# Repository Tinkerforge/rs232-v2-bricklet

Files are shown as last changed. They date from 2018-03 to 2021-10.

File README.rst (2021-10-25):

RS232 Bricklet 2.0
==================

This repository contains the firmware source code and the hardware design
files. The documentation generator configs can be found at
https://github.com/Tinkerforge/generators

Repository Content
------------------

software/:
 * examples/: Examples for all supported languages
 * build/: Compiled files
 * src/: Source code of firmware
 * Makefile: Makefile to build project

hardware/:
 * Contains KiCad project files and additionally schematics as PDF

datasheets/:
 * Contains datasheets for sensors and complex ICs that are used

Hardware
--------

The hardware is designed with the open source EDA Suite KiCad
(http://www.kicad.org). Before you are able to open the files,
you have to install the Tinkerforge kicad-libraries
(https://github.com/Tinkerforge/kicad-libraries). You can either clone
them directly in hardware/ or clone them in a separate folder and
symlink them into hardware/
(ln -s kicad_path/kicad-libraries project_path/hardware). After that you
can open the .pro file in hardware/ with KiCad and from there view and
modify the schematics and the PCB layout.

Software
--------

If you want to do your own Brick/Bricklet firmware development we highly
recommend that you use our build environment setup script and read the
tutorial (https://www.tinkerforge.com/en/doc/Tutorials/Tutorial_Build_Environment/Tutorial.html).

To compile the C code we recommend you to install the newest GNU Arm Embedded
Toolchain (https://launchpad.net/gcc-arm-embedded/+download).
You also need to install bricklib2 (https://github.com/Tinkerforge/bricklib2).

You can either clone it directly in software/src/ or clone it in a
separate folder and symlink it into software/src/
(ln -s bricklib_path/bricklib2 project_path/software/src/). Finally make sure to
have CMake installed (http://www.cmake.org/cmake/resources/software.html).

After that you can build the firmware by invoking make in software/.
The firmware (.zbin) can then be found in software/build/ and uploaded
with brickv (click button "Flashing" on start screen).

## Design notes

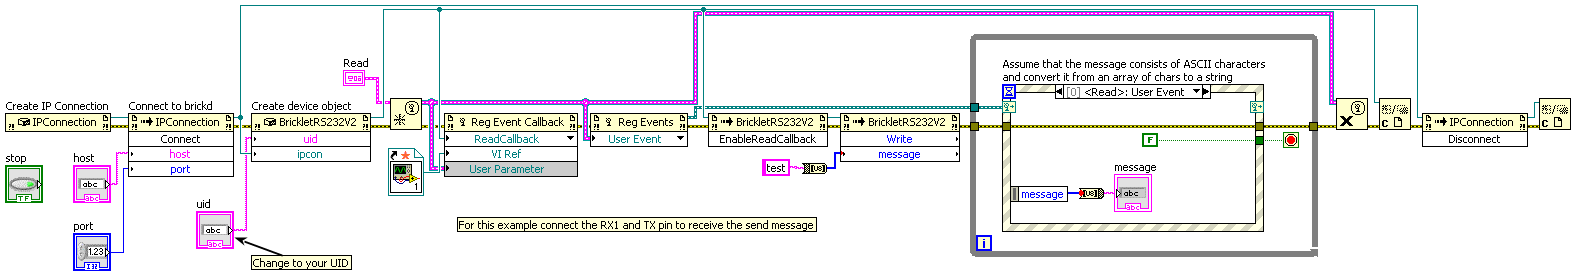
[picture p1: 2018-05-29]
software/examples/labview/Example Loopback.vi.png

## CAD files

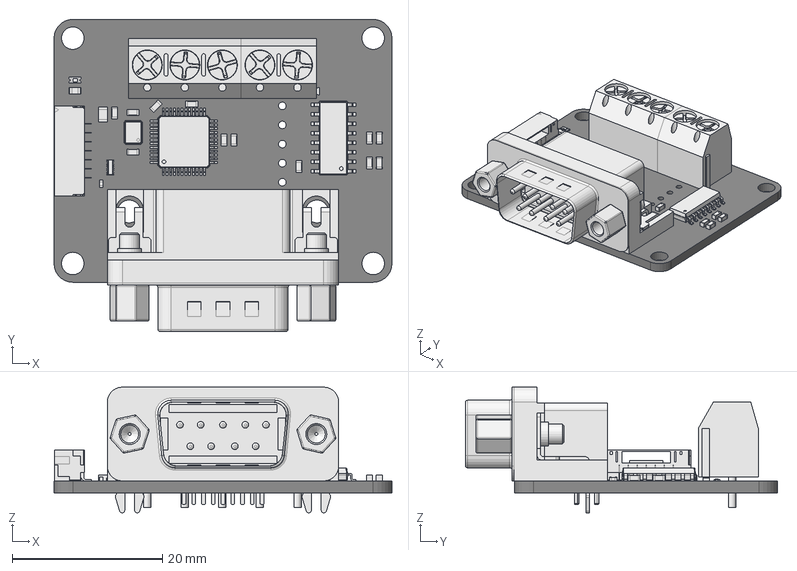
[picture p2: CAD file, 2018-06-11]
hardware/rs232-v2.FCStd
45.0 x 41.6 x 16.8 mm
Pcb
C_0603_
soic_16_39x99_p127_
lqfp48_7x7_p05_
BrickletConn_7pin_
D_0603_blue_
C_0603_001
C_0603_002
C_0603_003
C_0603_004
C_0603_005
C_0603_006
C_0603_007
C_0603_008
DSUB9-Male_
C_0402_
C_0603_009
C_0805_
C_0603_010
C_0603_011
R_0603_

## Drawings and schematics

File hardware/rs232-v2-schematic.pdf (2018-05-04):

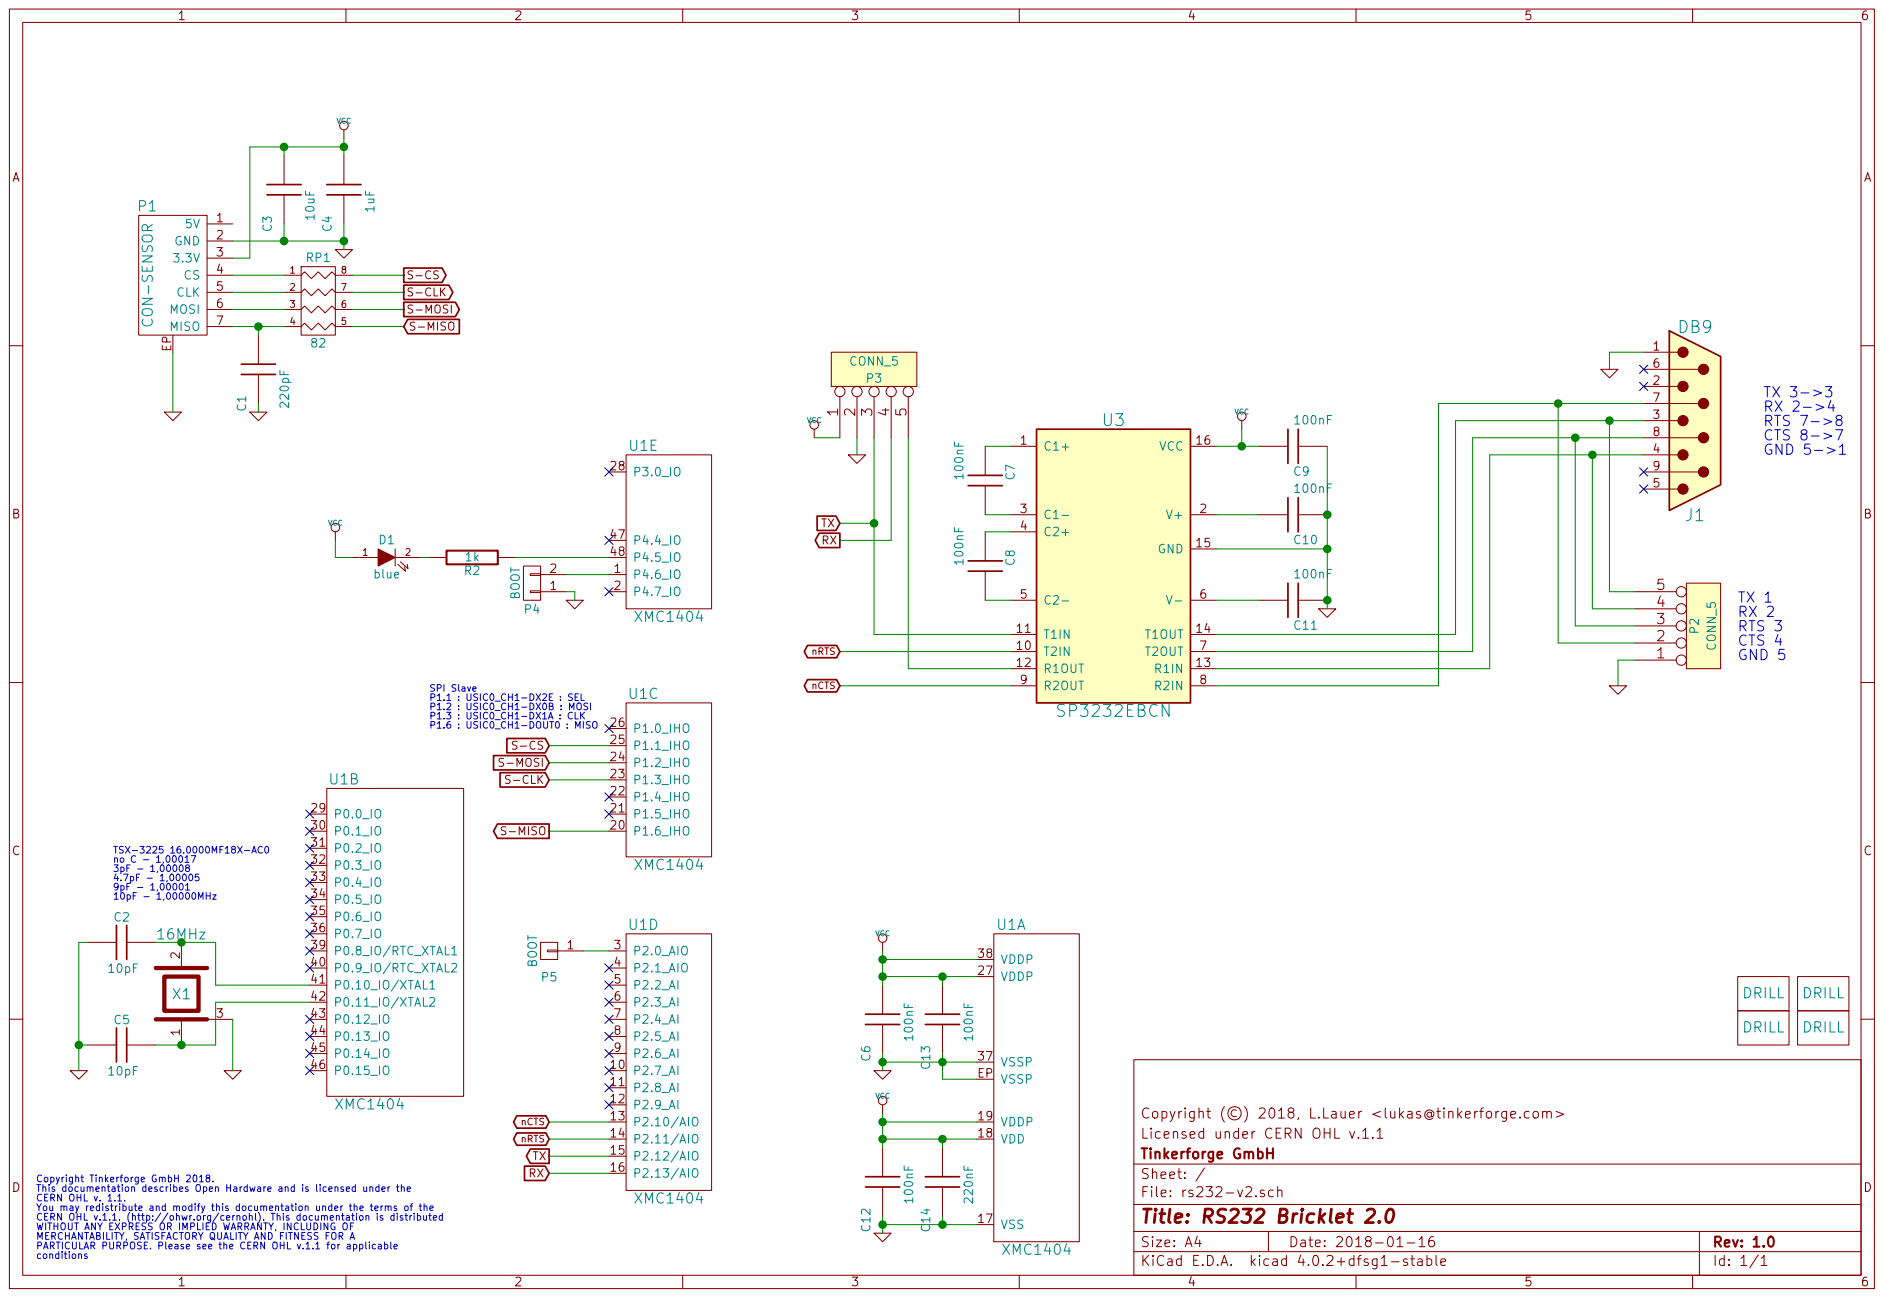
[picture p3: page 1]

GND 5->1 TX 1 RX 2 RTS 3

SPI Slave P1.1 : USIC0_CH1-DX2E : SEL P1.2 : USIC0_CH1-DX0B : MOSI P1.3 : USIC0_CH1-DX1A : CLK

Licensed under CERN OHL v.1.1 Copyright (©) 2018, L.Lauer <lukas@tinkerforge.com>

File: rs232-v2.sch Sheet: / Tinkerforge GmbH

Copyright Tinkerforge GmbH 2018. This documentation describes Open Hardware and is licensed under the CERN OHL v. 1.1. You may redistribute and modify this documentation under the terms of the CERN OHL v.1.1. (http://ohwr.org/cernohl). This documentation is distributed WITHOUT ANY EXPRESS OR IMPLIED WARRANTY, INCLUDING OF MERCHANTABILITY, SATISFACTORY QUALITY AND FITNESS FOR A

PARTICULAR PURPOSE. Please see the CERN OHL v.1.1 for applicable

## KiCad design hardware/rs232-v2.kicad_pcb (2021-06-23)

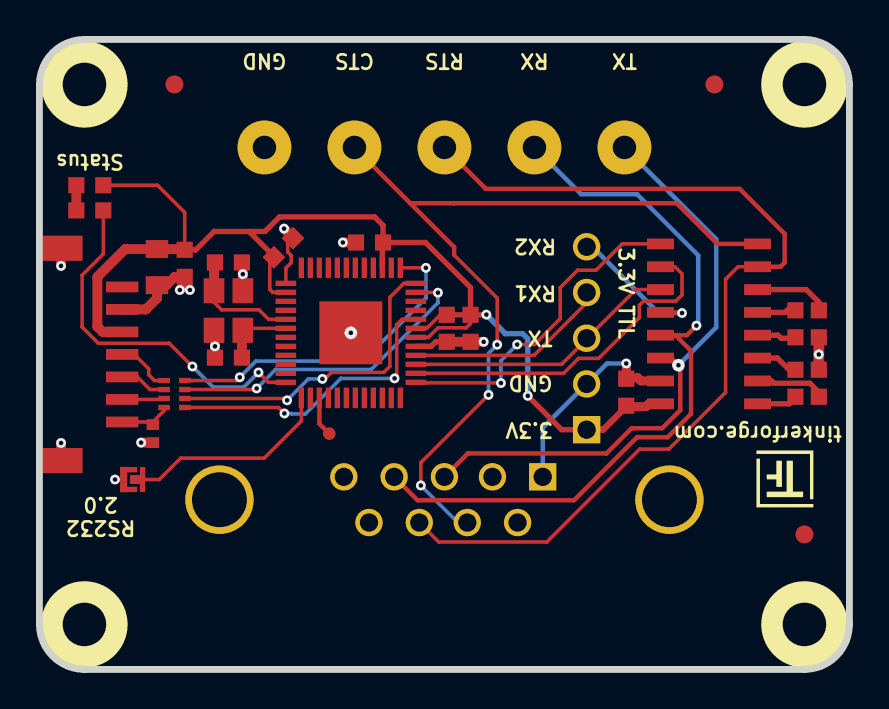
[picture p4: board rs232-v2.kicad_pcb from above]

Board: 2 copper layers, 45.0 x 35.0 mm, 35 parts (0 on the bottom side), 31 nets.

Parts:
C1: 220pF; C0402F
C2, C5: 10pF; C0603F
C3: 10uF; C0805
C4: 1uF; C0603F
C6, C7, C8, C9, C10, C11, C12, C13: 100nF; C0603F
C14: 220nF; C0603F
D1: blue; D0603F
Fiducial_Mark: VAL**; Fiducial_Mark
Fiducial_Mark#2, Fiducial_Mark#3: VAL**; Fiducial_Mark
J1: DB9; SUB09-EU
P1: CON-SENSOR; CON-SENSOR2
P2: CONN_5; AKL_5_5
P3: CONN_5; pin_array_5x1
P4: BOOT; SolderJumper
P5: BOOT; DEBUG_PAD
R2: 1k; R0603F
RP1: 82; 4X0402
U1: XMC1403; QFN48-EP2
U3: SP3232EBCN; SOIC16
U4, U5, U6, U7: DRILL; DRILL_NP
VAL: CE_5mm
VAL#2: WEEE_7mm
X1: 16MHz; CRYSTAL_3225

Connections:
GND: C1.1, C2.1, C3.1, C4.1, C5.1, C6.1, C9.1, C10.1, C11.1, C12.1, C13.1, C14.1, J1.1, P1.2, P1.EP, P2.1, P3.2, P4.1, U1.17, U1.37, U1.EP, U3.15, X1.3
unnamed: C1.2, P1.7, RP1.4
unnamed: C2.2, U1.41, X1.2
unnamed: C5.2, U1.42, X1.1
unnamed: C7.1, U3.1
unnamed: C7.2, U3.3
unnamed: C8.1, U3.4
unnamed: C8.2, U3.5
unnamed: C10.2, U3.2
unnamed: C11.2, U3.6
unnamed: D1.2, R2.2
unnamed: J1.3, P2.5, U3.14
unnamed: J1.4, P2.4, U3.13
unnamed: J1.7, P2.2, U3.8
unnamed: J1.8, P2.3, U3.7
unnamed: P1.4, RP1.1
unnamed: P1.5, RP1.2
unnamed: P1.6, RP1.3
unnamed: P3.5, U3.12
unnamed: P4.2, U1.1
unnamed: P5.1, U1.3
unnamed: R2.1, U1.48
RX: P3.4, U1.16
S-CLK: RP1.7, U1.23
S-CS: RP1.8, U1.25
S-MISO: RP1.5, U1.20
S-MOSI: RP1.6, U1.24
TX: P3.3, U1.15, U3.11
VCC: C3.2, C4.2, C6.2, C9.2, C12.2, C13.2, C14.2, D1.1, P1.3, P3.1, U1.18, U1.19, U1.27, U1.38, U3.16
nCTS: U1.13, U3.9
nRTS: U1.14, U3.10

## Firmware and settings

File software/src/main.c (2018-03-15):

/* rs232-v2-bricklet
 * Copyright (C) 2018 Ishraq Ibne Ashraf <ishraq@tinkerforge.com>
 *
 * main.c: Initialization for RS232 V2 Bricklet
 *
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
 * You should have received a copy of the GNU Lesser General Public
 * License along with this library; if not, write to the
 * Free Software Foundation, Inc., 59 Temple Place - Suite 330,
 * Boston, MA 02111-1307, USA.
 */

#include <stdio.h>
#include <stdbool.h>

#include "bricklib2/bootloader/bootloader.h"
#include "bricklib2/hal/system_timer/system_timer.h"
#include "bricklib2/logging/logging.h"

#include "configs/config.h"
#include "communication.h"
#include "rs232.h"

int main(void) {
	logging_init();
	logd("Start RS232 V2 Bricklet\n\r");

	communication_init();
	rs232_init();

	while(true) {
		rs232_tick();
		bootloader_tick();
		communication_tick();
	}
}

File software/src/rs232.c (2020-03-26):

/* rs232-v2-bricklet
 * Copyright (C) 2018 Ishraq Ibne Ashraf <ishraq@tinkerforge.com>
 *
 * rs232.c: RS232 V2 handling
 *
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
 * You should have received a copy of the GNU Lesser General Public
 * License along with this library; if not, write to the
 * Free Software Foundation, Inc., 59 Temple Place - Suite 330,
 * Boston, MA 02111-1307, USA.
 */

#include "rs232.h"

#include "bricklib2/hal/system_timer/system_timer.h"
#include "bricklib2/utility/ringbuffer.h"
#include "bricklib2/logging/logging.h"

#include "xmc_scu.h"
#include "xmc_usic.h"
#include "xmc_uart.h"

#include "communication.h"
#include "configs/config.h"

#define rs232_rx_irq_handler  IRQ_Hdlr_11
#define rs232_tx_irq_handler  IRQ_Hdlr_12
#define rs232_rxa_irq_handler IRQ_Hdlr_13

/*
 * Set const pointers to RX ringbuffer variables.
 * With this the compiler can properly optimize the access!
 */

// RX part of buffer always starts from 0.
uint8_t  *const rs232_rb_rx_buffer = &(rs232.buffer[0]);
uint16_t *const rs232_rb_rx_end = &(rs232.rb_rx.end);
uint16_t *const rs232_rb_rx_start = &(rs232.rb_rx.start);
uint16_t *const rs232_rb_rx_size = &(rs232.rb_rx.size);

RS232_t rs232;

void __attribute__((optimize("-O3"))) __attribute__ ((section (".ram_code"))) rs232_rx_irq_handler() {
	NVIC_DisableIRQ((IRQn_Type)RS232_IRQ_RX);
	NVIC_DisableIRQ((IRQn_Type)RS232_IRQ_RXA);

	while(!XMC_USIC_CH_RXFIFO_IsEmpty(RS232_USIC)) {
		uint8_t rx_byte = RS232_USIC->OUTR;
		uint16_t rb_rx_used = (*rs232_rb_rx_end < *rs232_rb_rx_start) ? \
		                      (*rs232_rb_rx_size + *rs232_rb_rx_end - *rs232_rb_rx_start) : \
		                      (*rs232_rb_rx_end - *rs232_rb_rx_start);

		if (rs232.flowcontrol != RS232_V2_FLOWCONTROL_OFF) {
			// Flow control enabled.
			if(rs232.flowcontrol == RS232_V2_FLOWCONTROL_SOFTWARE) {
				// Software flow control.
				if (rx_byte == FC_SW_XON) {
					rs232.fc_sw_state_tx = FC_SW_STATE_TX_OK;

					// We don't treat XON/XOFF control byte as data.
					continue;
				}
				else if (rx_byte == FC_SW_XOFF) {
					rs232.fc_sw_state_tx = FC_SW_STATE_TX_WAIT;

					// We don't treat XON/XOFF control byte as data.
					continue;
				}

				if((rs232.buffer_size_rx - rb_rx_used) <= FC_RB_RX_LIMIT) {
					// We can't RX more data.

					// TX XOFF from rs232_tick().
					rs232.fc_sw_tx_xoff = true;
					rs232.fc_sw_state_rx = FC_SW_STATE_RX_WAIT;
				}
			}
			else if(rs232.flowcontrol == RS232_V2_FLOWCONTROL_HARDWARE) {
				// Hardware flow control.
				if((rs232.buffer_size_rx - rb_rx_used) <= FC_RB_RX_LIMIT) {
					// We can't RX more data.

					/*
					 * XMC_GPIO_SetOutputHigh(RS232_RTS_PIN);
					 * |
					 * | ---> RS232 logic 0.
					 *
					 * XMC_GPIO_SetOutputLow(RS232_RTS_PIN);
					 * |
					 * | ---> RS232 logic 1.
					 */

					// De-assert RTS pin.
					XMC_GPIO_SetOutputHigh(RS232_RTS_PIN);
				}
			}
		}

		/*
		 * Instead of ringbuffer_add() we add the byte to the buffer by hand.
		 * We need to save the low watermark calculation overhead.
		 */
		uint16_t new_end = *rs232_rb_rx_end + 1;

		if(new_end >= *rs232_rb_rx_size) {
			new_end = 0;
		}

		if(new_end == *rs232_rb_rx_start) {
			rs232._error_count_overrun++;

			// In the case of an overrun we read the byte and throw it away.
			volatile uint8_t __attribute__((unused)) _  = RS232_USIC->OUTR;
		}
		else {
			//rs232_rb_rx_buffer[*rs232_rb_rx_end] = RS232_USIC->OUTR;
			rs232_rb_rx_buffer[*rs232_rb_rx_end] = rx_byte;
			*rs232_rb_rx_end = new_end;
		}
	}

	NVIC_EnableIRQ((IRQn_Type)RS232_IRQ_RX);
	NVIC_EnableIRQ((IRQn_Type)RS232_IRQ_RXA);
}

void __attribute__((optimize("-O3"))) __attribute__ ((section (".ram_code"))) rs232_tx_irq_handler() {
	while(!XMC_USIC_CH_TXFIFO_IsFull(RS232_USIC)) {
		// TX FIFO is not full, more data can be loaded on the FIFO from the ringbuffer.
		uint8_t data;

		if(rs232.flowcontrol != RS232_V2_FLOWCONTROL_OFF) {
			if(rs232.flowcontrol == RS232_V2_FLOWCONTROL_SOFTWARE) {
				if(rs232.fc_sw_state_tx == FC_SW_STATE_TX_WAIT) {
					XMC_USIC_CH_TXFIFO_DisableEvent(RS232_USIC,
					                                XMC_USIC_CH_TXFIFO_EVENT_CONF_STANDARD);

					return;
				}
			}
			else if(rs232.flowcontrol == RS232_V2_FLOWCONTROL_HARDWARE) {
				/*
				 * XMC_GPIO_GetInput(RS232_CTS_PIN);
				 * |
				 * | ---> Return = 0 = RS232 logic 1.
				 * | ---> Return = 1 = RS232 logic 0.
				 */
				if(XMC_GPIO_GetInput(RS232_CTS_PIN) == 1) {
					XMC_USIC_CH_TXFIFO_DisableEvent(RS232_USIC,
					                                XMC_USIC_CH_TXFIFO_EVENT_CONF_STANDARD);

					return;
				}
			}
		}

		if(!ringbuffer_get(&rs232.rb_tx, &data)) {
			// No more data to TX from the ringbuffer, disable TX interrupt.
			XMC_USIC_CH_TXFIFO_DisableEvent(RS232_USIC,
			                                XMC_USIC_CH_TXFIFO_EVENT_CONF_STANDARD);

			return;
		}

		RS232_USIC->IN[0] = data;
	}
}

void __attribute__((optimize("-O3"))) rs232_rxa_irq_handler() {
	/*
	 * We get alternate RX interrupt if there is a parity error.
	 * In this case we still read the byte and give it to the user.
	 */
	rs232_rx_irq_handler();

	rs232._error_count_parity++;
}
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

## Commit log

2018-01-16 Add initial schematic
    [rs232.sch]
2018-01-16 Remove cache lib
    [rs232.sch]
2018-01-16 Add pcb layout
    [rs232.kicad_pcb]
2018-01-16 Minor adjustments
    [rs232.kicad_pcb]
2018-01-19 remove 0 ohm resitor in crystal circuitry
    [rs232.kicad_pcb, rs232.sch]
2018-02-20 Cleanup KiCad libraries config
    Ensure LibDir=kicad-libraries and LibName1=tinkerforge.
    Remove special library.
2018-03-07 Add initial stub of RS232 V2 firmware
    [cmake_config_custom.txt]
2018-03-15 fix status text
    [rs232.kicad_pcb]
2018-03-15 drc check
    [rs232.kicad_pcb]
2018-03-16 Functional firmware implementation. Yet to implement:
    1. Flow control
    2. Tick based RX FIFO drain
2018-03-27 specify processor
    [rs232.kicad_pcb, rs232.sch]
2018-04-16 Add 3d information (final)
    [rs232.kicad_pcb]
2018-04-23 Add 3d model (*.FCStd & *.step)
    [rs232.FCStd]
2018-05-04 Rename files
    [rs232-v2.FCStd, rs232-v2.kicad_pcb, rs232-v2.sch]
2018-05-04 Add schematic PDF
2018-05-29 Define flash size to be 64KB
    [cmake_config_custom.txt]
2018-06-11 Fix 3d model
    [rs232-v2.FCStd, rs232-v2.kicad_pcb]
2018-06-18 Change capacitor footprint(s) to C0402F
    [rs232-v2.kicad_pcb, rs232-v2.sch]
2018-07-17 examples: Remove unnecessary length printing
2018-07-17 delphi: Use PChar instead of PAnsiChar
    With PAnsiChar the message "test" will be printed as "t e " in Delphi XE.
2020-02-14 Change available callback to frame readable.
    This now also reports the number of readable frames not readable bytes.
2020-02-25 Mutually exclude read/frame_readable callbacks.
2020-03-26 Configure TX pin high during configuration
    otherwise there can be glitches on TX line if configuration changes.
    [rs232.c]
2020-09-02 uc: Add example driver note.
2021-06-23 fix library, define xmc1403 as minimum instead of xmc1404
    [rs232-v2.kicad_pcb, rs232-v2.sch]
2021-06-23 Use XMC1403 as minimum requirement
    [cmake_config_custom.txt]
2021-10-25 Update KiCad link
    https://www.kicad.org/blog/2021/10/Avoid-links-to-former-kicad-domain/
2022-04-26 uc: Adapt to current bindings
